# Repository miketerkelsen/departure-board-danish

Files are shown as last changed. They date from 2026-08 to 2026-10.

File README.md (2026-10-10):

# departures-board 

This is an ESP32 based Departures Board for Danish public transport, using data from [Rejseplanen](https://www.rejseplanen.dk) (API 2.0), which covers almost all of Denmark's trains, S-tog, letbane/light rail and buses. It replicates the look of a real station departure board. This implementation uses a 3.12" OLED display panel with SSD1322 display controller onboard, plus an optional TTP223 touch sensor. STL files are also provided for 3D printing the custom desktop case.

## Features
* All processing is done onboard by the ESP32 processor, no middleware servers
* Support for a touch sensor to switch modes / stations / wake from screensaver
* Smooth animation matching real station departure boards
* Four board modes, all powered by Rejseplanen:
  * **Tog** - intercity/regional trains (IC, Lyntog, Regionaltog, Togbus, S-tog), filterable by train type
  * **S-tog** - a dedicated S-tog board with line-letter badges (e.g. A, C, Bx) and minute countdowns, so you can run it alongside Tog for the same or a different station
  * **Letbane** - light rail, with the current location of the next service optionally shown
  * **Bus** - bus stop departures
* Plus a Swedish mode, powered by [Trafiklab](https://www.trafiklab.se) (a separate, free API key):
  * **Tunnelbana** - Stockholm's metro, with round line badges (10, 11, 13, 14, 17, 18, 19), half-minute countdowns and the stops each train calls at. All on-screen text is Swedish. Tick Denmark and/or Sweden in the web configuration to choose which countries' modes are offered, and switch the board between them.
* Displays up to the next 9 departures with scheduled time, platform/track, destination, calling stations and expected/delayed departure time
* Optionally only show services heading towards a particular calling-at station (Tog mode)
* Scheduler and Carousel modes to automatically switch between any combination of configured stations/stops
* Fully-featured browser based configuration screens with live station search for all four modes
* Automatic firmware updates (optional), including daily update checks
* Displays the weather at the selected location (optional)
* Optionally display RSS headline feeds, with a built-in editor to add custom feeds
* Full-screen station clock (optional), including as a screensaver
* All on-screen text (including setup/error screens) is in Danish, with Danish and Swedish accented characters (æ ø å ä ö) supported
* STL files provided for a custom 3D printed case

## Quick Start

### What you'll need

1. An ESP32 D1 Mini board (or clone) - either USB-C or Micro-USB version with CH9102 recommended. For example, from [AliExpress](https://www.aliexpress.com/item/1005005972627549.html).
2. A 3.12" 256x64 OLED Display Panel with SSD1322 display controller onboard. For example, from [AliExpress](https://www.aliexpress.com/item/1005008558326731.html).
3. A 3D printed case using the STL files provided (see Credits below for where the original case design comes from). If you don't have a 3D printer, you can use a 3D print service, local library or group.
4. Optionally, a TTP223 touch sensor (for easily switching modes / stations). For example, from [AliExpress](https://www.aliexpress.com/item/1005007850732859.html). If fitted, the touch sensor should be glued to the inside of one of the walls of the top part of the case with the *sensor* side against the case.
5. A free Rejseplanen `accessId` from [Rejseplanen Labs](https://labs.rejseplanen.dk) - this is the only API key required, and covers all four board modes.
6. By default, weather data is sourced from Open-Meteo (no key needed). If you prefer to use OpenWeather (which usually provides slightly more localised weather conditions) you will need an OpenWeather Map API token (also free, sign up for a free developer account [here](https://home.openweathermap.org/users/sign_up)).
7. Some intermediate soldering skills.



### Preparing the OLED display for 4-Wire SPI Mode


As supplied, the display is usually shipped with 8-bit 80XX mode enabled. This needs to be changed to 4-Wire SPI mode by removing one link and adding another (the image shows where to make these changes on the rear of the circuit board).

### Wiring Guide

Solder the 4 SPI connections, plus power and ground. The wires **MUST** be soldered to the **BACK** of the ESP32 Mini board (the side without the components) to enable it to sit in place in the case. You can solder directly to the pins on the OLED screen or for the best fit (if you are a more experienced solderer) de-solder and remove the header pins and solder directly to the board. You cannot use Dupont connectors, they will not fit the custom case design.

| OLED Pin | ESP32 Mini Pin |
|:---|:---:|
| 1 VSS | GND |
| 2 VCC_IN | 3.3v |
| 4 D0/CLK | IO18 |
| 5 D1/DIN | IO23 |
| 14 D/C# | IO5 |
| 16 CS# | IO26 |

| TTP223 Pin | ESP32 Mini Pin |
|:---|:---:|
| 1 GND | GND |
| 2 I/O | IO34 |
| 3 VCC | 3.3v |



### Installing the firmware

The project uses the Arduino framework and the ESP32 v3.3.9 core. If you want to build from source, you'll need [PlatformIO](https://platformio.org). The software is designed for, and makes use of, a dual-core ESP32 processor. If you attempt to target and compile for a single core ESP32 variant the experience will be suboptimal at best.

You can download pre-compiled firmware images from the [releases](https://github.com/miketerkelsen/departure-board-danish/releases). These can be installed over the USB serial connection using [esptool](https://github.com/espressif/esptool). If you have python installed, install with *pip install esptool*. For convenience, a pre-compiled executable version for Windows is included [here](https://github.com/miketerkelsen/departure-board-danish/tree/main/esptool).

If the board is not recognised you are probably using a version with the CP2104 USB-to-Serial chip. Drivers for the CP2104 are [here](https://www.silabs.com/developer-tools/usb-to-uart-bridge-vcp-drivers?tab=downloads)

Attach the ESP32 Mini board via it's USB port and use the following command to flash the firmware:

```
esptool.py --chip esp32 --baud 460800 write_flash -z \
  0x1000 bootloader.bin \
  0xe000 boot_app0.bin \
  0x8000 partitions.bin \
  0x10000 firmware.bin
```

The tool should automatically find the correct serial port. If it fails to, you can manually specify the correct port by adding *--port COMx* (replace *COMx* with your actual port, e.g. COM3, /dev/ttyUSB0, etc.).

If using the pre-compiled esptool.exe version on Windows, save the esptool.exe and the four firmware (.bin) files to the same directory. Open a command prompt (Windows Key + R, type cmd and press enter) and change to the directory you saved the files into. Now type the following command on one line and press enter:
```
.\esptool --chip esp32 --baud 460800 write_flash -z 0x1000 bootloader.bin 0xe000 boot_app0.bin 0x8000 partitions.bin 0x10000 firmware.bin
```

Subsequent updates can be carried out automatically over-the-air or you can manually update from the Web GUI.

### First time configuration

WiFiManager is used to setup the initial WiFi connection on first boot. The ESP32 will broadcast a temporary WiFi network named "Departures Board" - connect to it and follow the on-screen instructions to join it to your own WiFi network.

Once the ESP32 has established an Internet connection, the next step is to enter your Rejseplanen API key (and, optionally, an OpenWeather Map key). Finally, select a station location for one of the four board modes - start typing the station name and valid choices will be shown as you type.

### Web GUI

At start-up, the ESP32's IP address is displayed. To change the station or to configure other miscellaneous settings, open the web page at that address.

- **Board Mode** - switch between Tog, S-tog, Letbane and Bus.
- **Station / S-tog Station / Letbane Stop / Bus Stop** - start typing a few characters of the name and select from the drop-down picker displayed. The field shown depends on the selected board mode.
- **Only show these train types** (Tog mode) - filter by category: IC, Lyntog (ICL), Regionaltog (Re), Togbus (rail-replacement bus) and S-tog.
- **Only show trains heading towards** (Tog mode) - optionally only show services heading towards a particular calling-at station.
- **Add to Scheduler** - adds the currently configured location to the scheduler (see Schedule tab) to switch based on time of day.
- **Add to Carousel** - adds the currently configured location to the carousel (see Schedule tab) to switch views after a period of time.

#### Options tab ####
- **Brightness** - adjusts the brightness of the OLED screen. Lowering it helps prevent burn-in.
- **Show the date on screen** - displays the date in the upper-right corner (useful if you're also using this as a desk clock).
- **Show current weather at station/bus stop** - optionally display weather conditions at the selected location.
- **Show station messages** (Tog/S-tog) - displays station and service status messages.
- **Show platform numbers if available** (Tog/S-tog) - deselecting this hides platform/track numbers.
- **Show service ordinal numbers** (Tog/S-tog) - displays "2nd", "3rd", "4th" etc. next to the service times.
- **Show service current location** (Letbane) - displays the origin of the primary service.
- **Wait for Calling at list to complete** (Tog/S-tog) - waits for the calling-at list to finish scrolling before changing the primary service.
- **Wait for Messages or RSS to complete** - waits for the current service message or RSS headline to finish scrolling before changing the primary service.
- **Full screen clock if no train services** - displays the full screen station clock if there are no scheduled services at the selected station.
- **Automatic firmware updates at startup** - automatically checks for and installs the latest firmware from this repository's [releases](https://github.com/miketerkelsen/departure-board-danish/releases) when the system starts up.
- **Daily check for firmware updates** - when enabled, the system also checks for and installs any updates just after midnight if the board is powered on.
- **Overnight sleep mode (screensaver)** - if you're running the board 24/7, this helps prevent screen burn-in overnight, with configurable start/end hours.
- **Switch off display during sleep mode** - turns off the display completely during sleep mode, otherwise displays the date & time.
- **Full screen clock during sleep mode** - displays the full screen station clock during sleep mode instead.

#### Schedule tab ####
- **Enable scheduler** - automatically switches between locations based on the configured time of each entry in the scheduler list (up to 5 entries).
- **Enable carousel** - automatically switches between locations based on the configured view time of each entry in the carousel list (up to 5 entries).

#### Advanced Tab ####
- **Enable touch sensor** - a tap switches between configured board modes, or wakes the board from sleep. If the Scheduler or Carousel is active, a tap switches to the next location instead. Requires an installed TTP223 sensor.
- **Wake from sleep by touch for** - if the board is in screensaver mode, a tap wakes it and it stays awake for the selected number of minutes (the timer resets on each tap).
- **Long press displays full screen clock** - a long tap switches to the full screen clock; a short tap reverts to normal operation.
- **Flip the display 180°** - rotates the display (the case design provides two different viewing angles depending on orientation).
- **Set custom hostname for board** - change the hostname from the default "DeparturesBoard", useful if you're running multiple boards.
- **Set custom (non-Danish) time zone** - only affects the clock display (see [below](#custom-time-zones) for details).
- **Suppress calling at / info messages** - turns off all horizontally scrolling text and RSS feeds (much lower functionality but less distracting).
- **Increase API refresh rate** - reduces the interval between data refreshes from every 90 seconds to every 45 seconds. Applies to all four modes; doubles Rejseplanen API usage, so worth leaving off if you're mindful of your API quota.
- **Show activity indicator during updates** - displays an icon while the board is communicating with Rejseplanen/weather/RSS.
- **Display RSS news headlines feed from** - shows the top headlines from the selected feed after other service messages. Use the RSS Feeds Editor to add your own feeds.
- **Prioritise RSS headlines feed** - displays headlines before other service messages.
- **Offset departures by** (Tog/S-tog) - displays future (or past) services offset by the selected time; does not affect the clock display.

A drop-down menu (top-right) adds the following options:
- **Check for Updates** - manually checks for and optionally installs any updates to the firmware. Also displays the release notes of the latest firmware.
- **Edit API Keys** - view/edit your Rejseplanen and OpenWeather Map API keys.
- **Edit RSS Feeds** - loads the RSS Feeds Editor where you can add/edit/delete custom headline feeds.
- **Clear WiFi Settings** - deletes the stored WiFi credentials and restarts in WiFiManager mode (useful to change WiFi network).
- **Restart System** - restarts the ESP32.

#### Other Web GUI Endpoints

A few other urls have been implemented, primarily for debugging/developer use:
- **/factoryreset** - deletes all configuration information, api keys and WiFi credentials. The entire setup process will need to be repeated.
- **/update** - for manual firmware updates. Download the latest binary from the [releases](https://github.com/miketerkelsen/departure-board-danish/releases). Only the **firmware.bin** file should be uploaded via */update*. The other .bin files are not used for upgrades. This method is *not* recommended for normal use.
- **/info** - displays some basic information about the current running state.
- **/formatffs** - formats the filing system, erasing the configuration files (but not the WiFi credentials).
- **/dir** - displays a (basic) directory listing of the file system with the ability to view/delete files.
- **/upload** - upload a file to the file system.
- **/control** - an endpoint for automation of sleep mode. Takes optional parameters *sleep* and *clock* - e.g. /control?sleep=1&clock=0 will force sleep mode and turn off the display completely. /control?sleep=0 will revert to normal operation. Always returns current state as json.

### Danish Rejseplanen Stop IDs
All four board modes use [Rejseplanen](https://www.rejseplanen.dk) (API 2.0). You'll need a free `accessId` from [Rejseplanen Labs](https://labs.rejseplanen.dk) - enter it as the "Rejseplanen API Key" on the API Keys screen. The web GUI's station search boxes handle finding stop IDs for you, but if you need to look one up manually: search for it on [rejseplanen.dk](https://www.rejseplanen.dk) and look at the departure board URL, or use a stop lookup tool such as [rejseplanen-cli](https://github.com/ndrdlc/rejseplanen-cli). Some stops (particularly letbane/light rail stops) have two IDs - one per direction of travel - but either one shows the full combined board with both directions, so it doesn't matter which you use. For example, Odense St. is `8600512` and Bolbro (Odense Letbane) is `8608704` or `8608754` - either works identically for Bolbro.

Danish æ/ø/å and Swedish ä/ö characters are supported directly on-screen (Swedish letters cover the occasional Swedish train passing through Denmark).

### Custom Time Zones
To set a custom time zone for the departure board clock, you will need to enter the POSIX time zone string for your location. Some examples are `CST6CDT,M3.2.0/2,M11.1.0/2` for Canada (Central Time), `AEST-10AEDT,M10.1.0,M4.1.0/3` for Australia (Eastern Time) and `CET-1CEST,M3.5.0,M10.5.0/3` for Denmark (Central European Time, the default). The easiest way to find the correct syntax is to ask your favourite AI chat engine *"What is the POSIX time zone string for ..."*. Note that changing the time zone only affects the clock (and date) display - service times are always shown in Danish local time, exactly as Rejseplanen returns them, regardless of the board's own clock time zone.

### Credits
This project is a Danish-focused fork of the original [Departures Board](https://github.com/gadec-uk/departures-board) by Gadec Software, including the OLED case design. This fork replaces the original UK Rail/Tube/Bus modes with Danish Rejseplanen-based modes (Tog, S-tog, Letbane, Bus) and translates the on-screen display to Danish.

### Licence
This work is licensed under **Creative Commons Attribution-NonCommercial-ShareAlike 4.0**. To view a copy of this licence, visit [https://creativecommons.org/licenses/by-nc-sa/4.0/](https://creativecommons.org/licenses/by-nc-sa/4.0/). Note: the terms of the licence prohibit commericial use of this work, this includes *any* reselling of the work in kit or assembled form for commercial gain.

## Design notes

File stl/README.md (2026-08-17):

# Departures Board Custom Case

This updated version of the custom case for the Departures Board is now compatible with both Micro-USB and USB-C versions of the processor board. The ESP32 D1 Mini processor is held securely in place by both halves of the case. The OLED screen should be a snug tight fit.  Optionally you may wish to fix the screen firmly in place with a few dabs from a hot glue gun (after fully testing!).

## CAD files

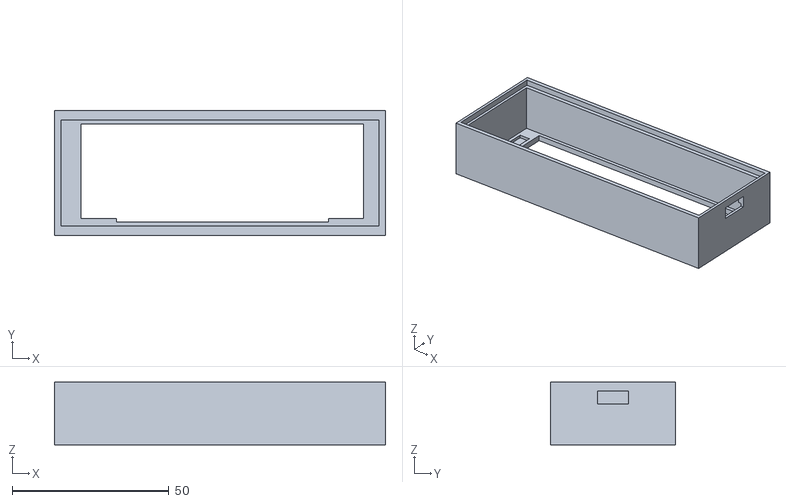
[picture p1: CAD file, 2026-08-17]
stl/Departures Board OLED Case Top v1.2.stl
105.5 x 39.7 x 20.0

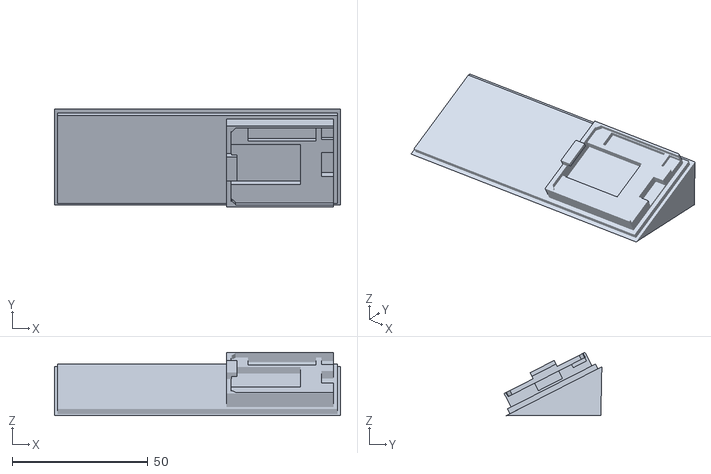
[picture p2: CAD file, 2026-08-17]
stl/Departures Board OLED Case Bottom v1.2.stl
105.5 x 36.1 x 23.4

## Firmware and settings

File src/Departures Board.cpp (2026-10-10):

/*
 * Departures Board (c) 2025-2026 Gadec Software
 *
 * https://github.com/gadec-uk/departures-board
 *
 * This work is licensed under Creative Commons Attribution-NonCommercial-ShareAlike 4.0 International.
 * To view a copy of this license, visit https://creativecommons.org/licenses/by-nc-sa/4.0/
 *
 * ESP32 "Mini" Board with 3.12" 256x64 OLED Display Panel with SSD1322 controller on-board.
 *
 * OLED PANEL     ESP32 MINI
 * 1 VSS          GND
 * 2 VCC_IN       3.3V
 * 4 D0/CLK       IO18
 * 5 D1/DIN       IO23
 * 14 D/C#        IO5
 * 16 CS#         IO26
 *
 * Optional TTP223 touch sensor connection:
 *
 * TTP223         ESP32 MINI
 * GND            GND
 * VCC            3.3V
 * I/O            IO34
 *
 */

#include <Arduino.h>
#include <WiFi.h>
#include <WiFiClientSecure.h>
#include <WiFiManager.h>
#include <AsyncTCP.h>
#include <ESPAsyncWebServer.h>
#include <StreamString.h>
#include <Ticker.h>
#include <HTTPClient.h>
#include <ESPmDNS.h>
#include <HTTPUpdateGitHub.h>
#include <FS.h>
#include <LittleFS.h>
#include <ArduinoJson.h>
#include <weatherClient.h>
#include <sharedDataStructs.h>
#include <responseCodes.h>
#include <boardText.h>
#include <rejseplanenClient.h>
#include <trafiklabClient.h>
#include <new>
#include <githubClient.h>
#include <rssClient.h>
#include <touchSensor.h>
#include <webgui/webgraphics.h>
#include <webgui/index.h>
#include <webgui/keys.h>
#include <webgui/editrss.h>
#include <webgui/rss.h>
#include <time.h>

#include <SPI.h>
#include <U8g2lib.h>

#define msDay 86400000 // 86400000 milliseconds in a day
#define msHour 3600000 // 3600000 milliseconds in an hour
#define msMin 60000 // 60000 milliseconds in a second

static AsyncWebServer server(80); // Hosting the Web GUI

// Shorthand for response formats
static const char contentTypeJson[] = "application/json";
static const char contentTypeText[] = "text/plain";
static const char contentTypeHtml[] = "text/html";

// Using NTP to set and maintain the clock
static struct tm timeinfo;
static const char defaultTimezone[] = "CET-1CEST,M3.5.0,M10.5.0/3"; // Denmark (CET/CEST)

// Default hostname
static const char defaultHostname[] = "DeparturesBoard";

// Local firmware updates via /update Web GUI
static const char updatePage[] =
"<script src='https://ajax.googleapis.com/ajax/libs/jquery/3.2.1/jquery.min.js'></script>"
"<html><body style=\"font-family:Helvetica,Arial,sans-serif\"><h2>Departures Board Manual Update</h2><p>Upload a <b>firmware.bin</b> file.</p>"
"<form method='POST' action='#' enctype='multipart/form-data' id='upload_form'>"
   "<input type='file' name='update'>"
        "<input type='submit' value='Update'>"
    "</form>"
 "<div id='prg'>progress: 0%</div>"
 "<script>"
  "$('form').submit(function(e){"
  "e.preventDefault();"
  "var form = $('#upload_form')[0];"
  "var data = new FormData(form);"
  " $.ajax({"
  "url: '/update',"
  "type: 'POST',"
  "data: data,"
  "contentType: false,"
  "processData:false,"
  "xhr: function() {"
  "var xhr = new window.XMLHttpRequest();"
  "xhr.upload.addEventListener('progress', function(evt) {"
  "if (evt.lengthComputable) {"
  "var per = evt.loaded / evt.total;"
  "$('#prg').html('Progress: ' + Math.round(per*100) + '%');"
  "}"
  "}, false);"
  "return xhr;"
  "},"
  "success:function(d, s) {"
  "console.log('success!')"
 "},"
 "error: function (a, b, c) {"
 "}"
 "});"
 "});"
 "</script></body></html>";

// /upload page
static const char uploadPage[] =
"<html><body style=\"font-family:Helvetica,Arial,sans-serif\">"
"<h2>Upload a file to the file system</h2><form method='post' enctype='multipart/form-data'><input type='file' name='name'>"
"<input class='button' type='submit' value='Upload'></form></body></html>";

// /success page
static const char successPage[] =
"<html><body style=\"font-family:Helvetica,Arial,sans-serif\"><h3>Upload completed successfully.</h3>\n"
"<p><a href=\"/dir\">List file system directory</a></p>\n"
"<h2>Upload another file</h2><form method=\"post\" action=\"/upload\" enctype=\"multipart/form-data\"><input type=\"file\" name=\"name\"><input class=\"button\" type=\"submit\" value=\"Upload\"></form>\n"
"</body></html>";

#define SCREEN_WIDTH 256 // OLED display width, in pixels
#define SCREEN_HEIGHT 64 // OLED display height, in pixels
#define DIMMED_BRIGHTNESS 1 // OLED display brightness level when in sleep/screensaver mode

U8G2_SSD1322_NHD_256X64_F_4W_HW_SPI u8g2(U8G2_R0, /* cs=*/ GPIO_NUM_26, /* dc=*/ GPIO_NUM_5, /* reset=*/ U8X8_PIN_NONE);

// Vertical line positions on the OLED display (National Rail)
#define LINE0 0
#define LINE1 13
#define LINE2 28
#define LINE3 41
#define LINE4 55

// Vertical line positions on the OLED display (Underground)
#define ULINE0 0
#define ULINE1 15
#define ULINE2 28
#define ULINE3 41
#define ULINE4 56

static Ticker restartTimer; // used to schedule reboots

//
// Custom fonts - replicas of those used on the real display boards
//
static const uint8_t NatRailSmall9[1329] U8G2_FONT_SECTION("NatRailSmall9") =
  "\221\0\3\2\4\4\4\5\5\11\11\0\0\11\0\11\2\1E\2\214\5\30 \5\0\230)!\7q("
  "%\6%\42\10\63h)\22K\0#\17u(mJI\62(\225A)%\11\0$\14u(\255\262"
  "\245\266%\311\26\1%\14t(+\42E\212\244H\221\2&\16u(m\244\222\224$R\22EJ\0"
  "'\6\61h%\6(\11s(\251\222R\255\0)\11s()\262R\245\4*\12U\70-\222\312b"
  "Y\32+\12U\70\255\302h\220\302\10,\7\62\10g\22\5-\6\23X)\6.\6\21(%\2/"
  "\13t(\353\42)\222\42)\3\60\12u(m\226\314[\262\0\61\11s)m\22\251\313\0\62\13u"
  "(m\226,\314\332\6\1\63\14u(m\226,\214T-Y\0\64\15u(\355\62))%\203\26&"
  "\0\65\13u(-\216C\32j\311\2\66\15u(m\226L\34\222LK\26\0\67\12u(-\6\61"
  "+\66\1\70\15u(m\226LK\226LK\26\0\71\15u(m\226LK\206PK\26\0:\7A"
  "\70%\242\0;\7R(gR\5<\10t(\353\242\306\6=\10\64H+\206p\10>\11t(+"
  "\302\246\66\0?\14u(m\226,\214\264\34\212\0@\14u(m\226\314\222(C\272\0A\13u("
  "m\226L\33\206\314\26B\15u(-\206$\323\6%\323\6\5C\13u(m\226LlK\26\0D"
  "\13u(-\206$\363\66(\0E\13u(-\216\341\220\204\341 F\13u(-\216\341\220\204E\0"
  "G\15u(m\226LL\206LK\26\0H\13u(-\62\333\60d\266\0I\7q(%\16\1J"
  "\11u(-;j\311\2K\15u(-\62))iIT\311\2L\11u(-\302\36\7\1M\13"
  "u(-\262eI\64\267\0N\13u(-\262II\244\315\26O\12u(m\226\314[\262\0P\14"
  "u(-\206$\323\6%,\2Q\13\225\10m\226\314[\62\246\1R\15u(-\206$\323\6\245T"
  "\311\2S\13u(m\226L]\265d\1T\11u(-\6)\354\11U\11u(-\62\337\222\5V"
  "\12u(-\62oI-\2W\13u(-\62\227DIn\1X\14u(-\62-\251UjZ\0"
  "Y\13u(-\62-\251\205M\0Z\12u(-\6\61\353\70\10[\10r('\226.\2\134\12t"
  "(+\62-\323\62-]\10r(\63\224.\3^\6#xi\32_\7\24\30+\206\0`\7\42x"
  "'\242\0a\12U(m\326d\320\222!b\13u(-\302\212I\323\6\5c\11U(m\6\261:"
  "\4d\13u(-+\246MK\206\0e\12U(m\226l\30\322!f\12t(\253*\245)+\1"
  "g\14u\10m\6\315\226\14\341\240\0h\12u(-\302\212I\263\5i\7q(%\222Aj\13\224"
  "\10\353r k\223\22\5k\13t(+\262\222\222HI)l\7q(%\16\1m\12U(m\272"
  "(\211\246\5n\11U(-\22\223f\13o\12U(m\226\314\226,\0p\14u\10-\206$\263\15"
  "J\30\2q\13u\10m\6\315\226\14a\1r\11U(-\22\223X\4s\11U(m\6\365\240\0"
  "t\13t(k\262hH\262\242\0u\11U(-\62'E\11v\12U(-\62[R\213\0w\14"
  "U(-\62%Q\22\245\13\0x\12U(-\262\244V\251\5y\13u\10-\62\267d\10\7\5z"
  "\11U(-\6\255m\20{\12s(\251\222(\311\242,|\7q(%\16\1}\13s()\262("
  "K\242$\2~\10%XmL\11\0\15u(-\222\254R\214\222(Q\12\200\5\0\10!\201\14"
  "e)\361\222A\213\262A\311\0\202\10B\10g*\12\0\203\5\0\10!\204\11D\10kzQ\22\0"
  "\205\7\25(-\222\2\206\15v(o\206$\64\16\17I\224\0\207\16w(\261\266\244)\262\250I\226"
  "M\0\210\21\210\30\63\323!\213\222d\213\262\245\224\15i\10\211\5\0\10!\212\5\0\10!\213\5\0"
  "\10!\214\5\0\10!\215\15u(/NK\242)C\62\14\2\216\16u(/\16\221\62(\203\42\15"
  "C\0\217\14w(\61\336\246\310\242n\303\1\220\6\63N?\36\221\7\62h'\222(\222\7\62hg"
  "\22\5\223\10\64h+\222\246$\224\10\64hkZ\224\4\225\6\63H)\36\226\7\25X-\6\1\227"
  "\5\0\10!\230\5\0\10!\231\5\0\10!\232\5\0\10!\233\5\0\10!\234\5\0\10!\235\5\0"
  "\10!\236\5\0\10!\237\5\0\10!\240\5\0\10!\241\5\0\10!\242\5\0\10!\243\14u(\255"
  "\244J\66Da\66\10\244\5\0\10!\245\5\0\10!\246\5\0\10!\247\5\0\10!\250\5\0\10!"
  "\251\5\0\10!\252\5\0\10!\253\5\0\10!\254\5\0\10!\255\5\0\10!\256\5\0\10!\257\5"
  "\0\10!\260\12DXk\224HJ\24\0\0\0\0";

static uint8_t NatRailTall12[1102] U8G2_FONT_SECTION("NatRailTall12") =
  "c\0\3\2\4\4\2\5\5\11\14\0\375\11\375\11\0\1Q\2\235\4\65 \5\0f\12!\7\221B"
  "\211C\22\42\7#^\212D\11#\21\225B\233R\222\14J)\211\222dPJI\2$\17\225B\253"
  "l)%\331\226DI\262E\0%\12\225B\313i\312:\35\1&\20\225B\33\251\22%Q$%\211"
  "\224D\221\22'\6!^\11\1(\11\223B\252\244\324\255\0)\11\223B\212\254\324\245\4*\14uF"
  "\253Je\261,M\21\0+\12UJ\253\60\32\244\60\2,\7\62\272\231D\1-\6\23R\212\1."
  "\6!B\11\1/\11\225B\313\266\216E\0\60\12\225B\233%\363[\262\0\61\11\223C\233D\352\313"
  "\0\62\13\225B\233%\13k\35\7\1\63\15\225B\233%\13Kj\250%\13\0\64\16\225B\273LJ"
  "JI\224\14ZX\1\65\15\225B\213c\70\244a\250%\13\0\66\15\225B\233%\23\303!\311l\311"
  "\2\67\15\225B\213A\254\205Y\230\205\31\0\70\15\225B\233%\263%KfK\26\0\71\15\225B\233"
  "%\263%C\30j\311\2:\6QJ\11E;\10b\306\231Z\242\0<\10t\306\272\250\261\1=\10"
  "\64\316\212!\34\2>\10t\306\212\260\251\15?\14\225B\233%\13k\305\34\212\0@\16\225B\233%"
  "\263$J\242\14a\272\0A\13\225B\233%\263\15C\346\26B\15\225B\213!\311l\203\222\331\6\5"
  "C\13\225B\233%\23{K\26\0D\13\225B\213!\311\374\66(\0E\13\225B\213cqH\302\342"
  " F\13\225B\213cqH\302F\0G\14\225B\233%\23K\233-Y\0H\13\225B\213\314m\30"
  "\62\267\0I\6\221B\211\7J\11\225B\313>j\311\2K\16\225B\213\60\223\222\222\246%Q%\13"
  "L\11\225B\213\260\37\7\1M\14\225B\213lY\22%\321\274\5N\15\225B\213l\232\224DI\244"
  "\233\26O\12\225B\233%\363[\262\0P\14\225B\213!\311l\203\22\66\2Q\13\265:\233%\363["
  "\62\246\1R\16\225B\213!\311l\203R\252dZ\0S\14\225B\233%S\325\242\226,\0T\11\225"
  "B\213A\12\373\11U\11\225B\213\314\337\222\5V\12\225B\213\314oI-\2W\13\225B\213\314\227"
  "DIn\1X\16\225B\213LKJIV\211\222\232\26Y\14\225B\213LKJI\26v\2Z\13"
  "\225B\213A\254u\14\7\1[\10\222\302\211\245/\2\134\11\225B\213\260\332\261\0]\10\222\302\11\245"
  "/\3^\6#^\232\6_\6\25>\213A`\6\42\336\211(a\13eB\233\65\31\64-\31\2b"
  "\14\225B\213\260\305\244i\223\242\0c\11eB\233Al\35\2d\13\225B\313\26\323fR\224\0e"
  "\14eB\233%\33\206\60K\26\0f\13\224\302*%\213\206$\353\4g\15\225\66\33\323fR\224P"
  "K\26\0h\12\225B\213\260\305\244\271\5i\7\201B\211d\30j\13\264\266\272\34\310z\223\22\5k"
  "\15\225B\213\260))iIT\311\2l\6\221B\211\7m\15eB\13\245EI\224DI\224\2n"
  "\11eB\213\304\244\271\5o\12eB\233%sK\26\0p\15\225\66\213\304\244i\223\242\204E\0q"
  "\13\225\66\33\323fR\224\260\1r\11eB\213\304$\66\2s\12eB\233%]\265d\1t\12\204"
  "\302\232,\32\222\254Qu\11eB\213\314\223\242\4v\14eB\213LKJI\26F\0w\16eB"
  "\213$Q\22%Q\22\245\13\0x\13eB\213,\251\205YR\13y\14\225\66\213\314\223\242\204Z\262"
  "\0z\12eB\213A\314\332\6\1{\21\227B\234,\321\226\245\247\310\242&Y\222,\1|\6\221B"
  "\213\7}\17\266\66\273\70\31\306:\26\206\303\22g\0~\21\226\302\233!\31\206P\34\36\24e\30\222"
  "(\1\16\226\302\213$\314\224(\315\222,\351?\200\24\231B\255AK\223L\222B)\224BMJ"
  "\322l\220\0\201\24\231>\255AK\223,\323\62-\323\26\35H\322l\220\0\202\22\231>\335t\320*"
  "\311\30\245Q\270\324\262AM\1\0\0\0";

static const uint8_t NatRailClockSmall7[137] U8G2_FONT_SECTION("NatRailClockSmall7") =
  "\12\0\3\3\3\3\3\1\5\7\7\0\0\7\0\7\0\0\0\0\0\0p\60\12?\343Td\274I*"
  "\0\61\10\274\343HF\272\20\62\13?\343TdRIE*=\63\14?\343TdR\331\230&\251\0"
  "\64\14?\343\315H\22%\311Q*\1\65\13?c\34\244f)MR\1\66\14?\343TdT\213\214"
  "&\251\0\67\11?c\134\205Z\325\0\70\15?\343Td\64IEF\223T\0\71\14?\343Td\64"
  "\211\225&\251\0\0\0\0";

static const uint8_t NatRailClockLarge9[177] U8G2_FONT_SECTION("NatRailClockLarge9") =
  "\13\0\4\3\4\4\3\2\5\11\11\0\0\11\0\11\0\0\0\0\0\0\230\60\13\231T\307\205\24\277\222"
  "\270\0\61\11\224W\207\304\210\276 \62\16\231T\307\205\224\234\212\13\71u\7\2\63\17\231T\307\205\224"
  "\234\232B\71*\211\13\0\64\23\231T\327\24\221\204\214\210\32\11!\211\3\61\71\11\0\65\20\231T\307"
  "\301\234\334A\240\34\25\225\304\5\0\66\20\231T\307\205\24\235\334A\204\24+\211\13\0\67\14\231T\303"
  "\201\234\252Ur\32\1\70\17\231T\307\205\24+\211\13)V\22\27\0\71\20\231T\307\205\24+\211\203"
  "\70\71*\211\13\0:\7r\235\2\31\1\0\0\0";

static const uint8_t Underground10[1335] U8G2_FONT_SECTION("Underground10") =
  "\221\0\3\2\3\4\4\5\5\11\12\0\377\11\377\11\0\1^\2\310\5\36 \5\0\314\25!\7I\204"
  "\22\207$\42\7\23\274\24\211\22#\21M\204\66\245$\31\224R\22%\311\240\224\222\4$\17M\204V"
  "\331RJ\262-\211\222d\213\0%\12M\204\226\323\224u:\2&\17F\204\67Z\324\246E\211\226D"
  "I\42\5'\10\42\254\23C\242\0(\10J\204\63J\237\2)\11J\204\23Q\322\213\2*\14=\214"
  "V\225\312AY\232\42\0+\12-\224Va\64Ha\4,\10\42|\23C\242\0-\7\15\244\26\203"
  "\0.\7\22\204\23C\0/\10?\214\327i\237\1\60\14N\204\67C\22\372\61\31\22\0\61\7J\205"
  "\67K?\62\14N\204\67C\22\246\305\216\303\0\63\16N\204\67C\22\246\245\71\25\223!\1\64\16N"
  "\204\227\241\226D\225,\31\306\264\2\65\16N\204\27\207\64\35\344\64\25\223!\1\66\17N\204\67C\22"
  "\252\351\240\204\306dH\0\67\12N\204\27\327b\257)\0\70\17N\204\67C\22\32\223!\11\215\311\220"
  "\0\71\17N\204\67C\22\32\223AM\305dH\0:\10\62\214\23C\70\4;\11:\204\23C\250("
  "\0<\10<\214uQc\3=\10\34\234\25C\70\4>\11<\214\25aS\33\0?\15M\204\66K"
  "\246\205Y\61\207\42\0@\16M\204\66KfI\224D\31\302t\1A\14N\204\67C\22\32\207At"
  "\14B\16N\204\27\203\22\32\207%\64\16\13\0C\14N\204\67C\22\252=&C\2D\13N\204\27"
  "\203\22\372qX\0E\14N\204\27\207\264:\14iu\30F\14N\204\27\207\264:\14i+\0G\16"
  "N\204\67C\22\252\225A\64&C\2H\13N\204\27\241\343\60\210\216\1I\11K\204\24K\324\227\1"
  "J\12M\204\226=jZ\262\0K\20N\204\27\241\226D\225LL\262\250\226\204\1L\11N\204\27i"
  "\277\16\3M\16O\204\30\351\266T\244H\212T\327\0N\15N\204\27\241\270)\221\224h\243\61O\14"
  "N\204\67C\22\372\61\31\22\0P\14N\204\27\203\22\32\207%m\5Q\14V|\67C\22\372)I"
  "\206\70R\16N\204\27\203\22\32\207\245\26\325\222\60S\17N\204\67C\22\252\361\20\247b\62$\0T"
  "\12O\204\30\207,\356\67\0U\12N\204\27\241?&C\2V\14O\204\30\251\257IVI\63\0W"
  "\16O\204\30\251\247H\212\244H\351\226\0X\16O\204\30\251\232d\225\264\222UR\65Y\14O\204\30"
  "i\222U\322\270\67\0Z\13O\204\30\207\70\355\363\60\4[\10J\204\23K_\4\134\11M\204\26a"
  "\265c\1]\10J\204\23J_\6^\6\23\274\64\15_\7\15|\26\203\0`\7\42\254\23\203\24a"
  "\13\65\214\66k\62hZ\62\4b\14E\214\26a\70$\231\333\240\0c\12\65\214\66K&\326\222\5"
  "d\13E\214\226\225AsK\206\0e\14\65\214\66K\66\14a\226,\0f\13L\204UJ\26MY"
  "'\0g\14E|\66K\346\226\14a\262\0h\13M\204\26a\70$\231o\1i\7A\214\22\311\60"
  "j\11S|Ti\324\323\2k\15E\214\26a))iIT\311\2l\10C\214\24Q\337\4m\16"
  "\67\214\30\213\22ER$ER$\25n\11\65\214\26C\222y\13o\12\65\214\66K\346\226,\0p"
  "\14E|\26C\222\271\15J\30\2q\13E|\66K\346\226\14a\1r\12\64\214\25\311\20em\0"
  "s\12\65\214\66K\272j\311\2t\13D\214\65Y\64$Y\243\0u\11\65\214\26\231\267d\10v\12"
  "\65\214\26\231[R\213\0w\13\67\214\30\251S\244tK\0x\13\65\214\26YR\13\263\244\26y\13"
  "E|\26\231\267d\10\7\5z\12\65\214\26\203V\314\262A{\13K\204TIT\311\242Z\0|\6"
  "I\204\26\17}\13K\204\24YTK\242J\4~\21N\204\67C\62\14\241\70<(\312\60$Q\2"
  "\16N\204\27I\230)Q\232%Y\322\200\5\0\204\20\201\10\25\204\26I\242\24\202\5\0\204\20"
  "\203\5\0\204\20\204\5\0\204\20\205\5\0\204\20\206\5\0\204\20\207\5\0\204\20\210\5\0\204\20\211\5"
  "\0\204\20\212\5\0\204\20\213\5\0\204\20\214\5\0\204\20\215\5\0\204\20\216\5\0\204\20\217\5\0\204"
  "\20\220\6\33\237\37\17\221\5\0\204\20\222\5\0\204\20\223\5\0\204\20\224\5\0\204\20\225\5\0\204\20"
  "\226\5\0\204\20\227\5\0\204\20\230\5\0\204\20\231\5\0\204\20\232\5\0\204\20\233\5\0\204\20\234\5"
  "\0\204\20\235\5\0\204\20\236\5\0\204\20\237\5\0\204\20\240\5\0\204\20\241\5\0\204\20\242\5\0\204"
  "\20\243\14=\214VR%\33\242\60\33\4\244\5\0\204\20\245\5\0\204\20\246\5\0\204\20\247\5\0\204"
  "\20\250\5\0\204\20\251\5\0\204\20\252\5\0\204\20\253\5\0\204\20\254\5\0\204\20\255\5\0\204\20\256"
  "\5\0\204\20\257\5\0\204\20\260\12-\244\66KfK\26\0\0\0\0";

static const uint8_t UndergroundClock8[150] U8G2_FONT_SECTION("UndergroundClock8") =
  "\13\0\3\3\3\4\2\2\5\7\10\0\0\10\0\10\0\0\0\0\0\0}\60\12G\305\251\310\370&\251"
  "\0\61\10\304\305\222\234\364\0\62\15G\305\251\310\244B\331L(;\10\63\15G\305\251\310\244\42\62\215"
  "&\251\0\64\15G\305\24\316H\22%\311Q*\1\65\14G\305\70\310\250f\32MR\1\66\14G\305"
  "\251\310\250\26\31\233\244\2\67\12G\305\70\310\204z\225\2\70\15G\305\251\310h\222\212\214MR\1\71"
  "\15G\305\251\310h\22+\215&\251\0:\6\262\257 \22\0\0\0";
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
void loop(void) {

  if (touchEnabled) button.updateTouchState();

  if (button.wasShortTapped()) {
    if (isSleeping) {
      if (NSEclockIsActive) NSEclockIsActive = false;
      else forcedAwake = true;
    } else {
      switchToNextMode();
    }
  } else if (button.wasLongTapped() && longPressClock) {
    NSEclockIsActive = !NSEclockIsActive;
  }

  // Heap fragmentation self-heal. The secure fetch needs one ~20KB contiguous block (see
  // MIN_SAFE_HEAP_FOR_FETCH); after hours of TLS handshakes the free memory can still total 45KB+ yet be
  // in pieces too small for that, at which point every fetch is skipped and the board runs on stale data
  // forever (seen: largest block 2.6KB, nothing fetched for 13 minutes, until someone power-cycled it).
  // Fragmentation never clears by itself, so if it has blocked fetching for ten solid minutes, restart.
  // Checked only every 10s; the restart happens between fetches so it can't interrupt one mid-flight.
  static unsigned long lowHeapSince = 0, nextHeapCheck = 0;
  if (millis() > nextHeapCheck) {
    nextHeapCheck = millis() + 10000UL;
    if (heap_caps_get_largest_free_block(MALLOC_CAP_8BIT) < MIN_SAFE_HEAP_FOR_FETCH) {
      if (!lowHeapSince) lowHeapSince = millis();
      else if (millis() - lowHeapSince > 600000UL && !fetchInProgress) ESP.restart();
    } else lowHeapSince = 0;
  }

  if (millis()-lastTimeUpdate >= 100) {
    // Update the current time
    int prevSecond = timeinfo.tm_sec;
    if (getLocalTime(&timeinfo)) {
      sprintf(currentTime,"%02d:%02d:%02d",timeinfo.tm_hour,timeinfo.tm_min,timeinfo.tm_sec);
      lastTimeUpdate = millis();
      if (millis()>3888000000 && timeinfo.tm_hour==3) ESP.restart(); // Reboot every 45 days at 3am
      if (isSleeping && (useNSEclockForSleep || NSEclockIsActive) && prevSecond != timeinfo.tm_sec) drawNSEclock();  // Update the large clock
    }
  }

  // Check for firmware updates daily if enabled
  if (dailyUpdateCheck && !fetchInProgress && millis()>fwUpdateCheckTimer) {
    fwUpdateCheckTimer = millis() + 3300000 + random(600000); // check again in 55 to 65 mins
    if (timeinfo.tm_mday != prevUpdateCheckDay) {
      if (ghUpdate.getLatestRelease()==UPD_SUCCESS) {
        checkForFirmwareUpdate();
      }
      prevUpdateCheckDay = timeinfo.tm_mday;
    }
  }

  bool wasSleeping = isSleeping;
  isSleeping = isSnoozing();

  if (isSleeping && !useNSEclockForSleep && !NSEclockIsActive && millis()>timer) {       // If the "screensaver" is active, change the screen every 8 seconds
    drawSleepingScreen();
    timer=millis() + SCREENSAVERINTERVAL;
  } else if (wasSleeping && !isSleeping) {
    // Exit sleep mode cleanly
    softResetBoard(MODE_LOADCONFIG);
  } else if (isSleeping && !wasSleeping && useNSEclockForSleep && !NSEclockIsActive) u8g2.setContrast(DIMMED_BRIGHTNESS);

  // WiFi Status icon
  if (WiFi.status() != WL_CONNECTED && wifiConnected) {
    wifiConnected=false;
    u8g2.setFont(NatRailSmall9);
    u8g2.drawStr(0,56,"\x7F");  // No Wifi Icon
    u8g2.updateDisplayArea(0,7,1,1);
  } else if (WiFi.status() == WL_CONNECTED && !wifiConnected) {
    wifiConnected=true;
    blankArea(0,57,5,7);
    u8g2.updateDisplayArea(0,7,1,1);
    updateMyUrl();  // in case our IP changed
  }

  // Force a manual reset if we've been disconnected for more than 10 secs
  if (WiFi.status() != WL_CONNECTED && millis() > lastWiFiReconnect+10000) {
    WiFi.disconnect();
    delay(100);
    WiFi.reconnect();
    lastWiFiReconnect=millis();
  }

  switch (boardMode) {
    case MODE_DKRAIL:
      departureBoardLoop();
      break;

    case MODE_LETBANE:
      undergroundArrivalsLoop();
      break;

    case MODE_DKBUS:
      if (strcmp(locationCode,ODENSE_ST_ID)==0) odenseBusLoop(); else busDeparturesLoop();
      break;

    case MODE_STOG:
      departureBoardLoop();
      break;

    case MODE_METRO:
      departureBoardLoop();
      break;

    case MODE_SE_METRO:
      departureBoardLoop();
      break;
  }

  if (manualUpdateCheck && !fetchInProgress) doManualOtaCheck();

  if (rssEnabled && boardMode != MODE_DKBUS && millis() > nextRssUpdate && !fetchInProgress && !isSleeping && wifiConnected) {
    // Start an RSS Update on Core 0
    fetchMode = FETCH_RSS;
    fetchInProgress = true;
    xTaskNotifyGive(fetchTaskHandle);
  }

  if (rssFetchComplete) {
    // Background fetch has completed
    rssFetchComplete = false;
    if (lastRssUpdateResult == UPD_SUCCESS) buildRssMessage();
  }

  if (weatherEnabled && millis()>nextWeatherUpdate && !fetchInProgress && locationLat && locationLon && !isSleeping && wifiConnected) {
    // Start a weather update on Core 0
    fetchMode = FETCH_WEATHER;
    fetchInProgress = true;
    xTaskNotifyGive(fetchTaskHandle);
  }

  if (weatherFetchComplete) {
    weatherFetchComplete = false;
    if (lastWeatherUpdateResult == UPD_SUCCESS) {
      strlcpy(weatherMsg,currentWeather.currentWeatherMessage,MAXWEATHERSIZE);
    } else {
      weatherMsg[0] = '\0';
    }
  }

  if (softResetNeeded && !fetchInProgress) {
    softResetNeeded=false;
    softResetBoard(MODE_LOADCONFIG);
  }

  if ((schedulerActive || (carouselActive && numCarouselSlots>1)) && !isSleeping && !fetchInProgress && millis() > nextSchedulerCheck) {
    int nowTime = getTimeInMinutes();
    if ((activeSlotEventTime < nextSlotEventTime && nowTime >= nextSlotEventTime) || (activeSlotEventTime > nextSlotEventTime && nowTime < activeSlotEventTime && nowTime >= nextSlotEventTime)) {
      if (carouselActive) currentCarouselSlot = (currentCarouselSlot + 1) % numCarouselSlots;
      softResetBoard(MODE_LOADCONFIG);
    }
    nextSchedulerCheck = millis() + 10000;  // ten seconds
  }

}

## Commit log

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2026-08-17 Add DK Bus mode for touch-cycling train/bus/tram at one station
    - New MODE_DKBUS (bitmask 32 = Bus, catCode 5), mirroring the UK bus
    board layout via rejseplanenClient, same pattern as DKRAIL/LETBANE
    - Wired through every mode switch site (loadSlot cycle + fields,
    softResetBoard, fetchDeparturesTask, drawStationHeader, updateBusDepartures,
    loop dispatch, /info, error screens, RSS exclusions)
    - Also fixed a gap from the original DKRAIL/LETBANE work: the boot-time
    init block in setup() never had DKRAIL/LETBANE cases either - added
    DKRAIL/LETBANE/DKBUS there too
    - Danish "Forventet"/"Aflyst"/"Rettidig" status text and "no scheduled
    services" message translated for DK Bus, matching D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
    [Departures Board.cpp]
2026-08-17 Fix DK Bus etd overflow and switch Letbane to computed minutes-remaining
    - drawBusService(): etdWidth was hardcoded to 47px, sized for the short
    English "Exp HH:MM" - the much longer Danish "Forventet HH:MM" ran
    past the right edge of the screen. Now measured dynamically for
    MODE_DKBUS via getStringWidth(), matching the pattern already used
    for the cancelled/on-time text branch.
    - drawUndergroundService(): Letbane now shows a computed "X min"/"Nu"
    countdown (derived from each service's time vs. the board's own
    clock) instead of a bare clock time, matching the tube board's style
    more closely per user preference - Rejseplanen doesn't provide a
    live countdown value directly, unl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
    [Departures Board.cpp]
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2026-08-17 Switch Danish accent glyphs to per-character mixing; remove Rejseplanen attribution
    - Replace the earlier whole-font-swap approach for aeoeaa/AEOEAA rendering with
    character-level mixing (drawMixedStr/getMixedStringWidth/centreMixedText/
    drawTruncatedMixedText): the original hand-built fonts (NatRailSmall9,
    NatRailTall12, Underground10) are kept as the base font everywhere, and only
    the six accented bytes borrow a matching-height stock U8g2 font
    (u8g2_font_5x8_tf / _6x12_tf / _6x10_tf) for that single glyph. Fixes the
    reported scrolling-text glitch, which was a font-height mismatch (10px stock
    font vs a hardcoded 9px blankArea clear) leaving ghost pixel rows.
    - Apply the mixed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
    [Departures Board.cpp]
2026-08-17 Fix screensaver date running off screen edge
    drawSleepingScreen() measured sysDate's width with whatever font happened to
    be active beforehand (line 912) and then with NatRailClockLarge9 - the big
    clock digit font, not the one sysDate is actually drawn with (line 915) -
    before finally switching to NatRailSmall9 to draw it. The mismeasured width
    fed into the random x-position calculation, so the string (most visibly
    Danish full month names like 'august'/'september') could run past the right
    edge of the screen. Now measures with NatRailSmall9 up front, matching the
    font used to draw it.
    [Departures Board.cpp]
2026-08-17 Skip the dead line-3 cycle slot left by removing DK Rail attribution
    departureBoardLoop()'s additional-service rotation assumed the mandatory
    attribution slot always existed beyond the departure list, so it kept
    cycling through a now-blank slot for DK Rail (which has no attribution and,
    when weather is off, no weather message either) before wrapping back to the
    2nd departure - showing as a black gap between the 9th and 2nd departures.
    Rollover now sizes to the number of extra slots that actually have content
    (weather if enabled, attribution only for non-DK-Rail modes), so DK Rail
    with no weather skips straight from the last departure back to the 2nd.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
    [Departures Board.cpp]
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2026-08-17 Fix getMixedStringWidth systematically under-measuring text width
    u8g2.getStrWidth() (called per-character in a loop) special-cases the LAST
    character of whatever string it's given: it measures that one character's
    tight glyph pixel width instead of its full advance width, to avoid counting
    trailing letter-spacing past the true end of a string. Looping getStrWidth()
    over one-character substrings (as getMixedStringWidth did) makes every single
    character get that tight treatment instead of just the true last one, so the
    returned total undercounts the width drawMixedStr() actually draws (which
    sums the full per-glyph advance width throughout, matching what a single
    whole-string drawStr() call w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
    [Departures Board.cpp]
2026-08-17 Fix remaining off-by-one in DK Rail line-3 rollover (still-blank slot)
    The extraSlots rollover from the previous fix counted the right number of
    "extra" content slots (weather/attribution) but compared with '>' instead of
    '>=' against numServices+extraSlots - the extra slots actually occupy indices
    numServices..numServices+extraSlots-1, so '>' let line3Service reach one
    index past the last real slot before wrapping, regardless of extraSlots.
    That's what still showed as a blank 3rd-row beat between the last departure
    and the 2nd on DK Rail even after the earlier fix. Using '>=' wraps exactly
    at the right point - straight from the last departure back to the 2nd when
    there's no weather message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
    [Departures Board.cpp]
2026-08-17 Fix Danish accent glyph size and vertical alignment
    Two related issues with the mixed-glyph rendering (drawMixedStr/
    getMixedStringWidth):
    1. Root cause of the vertical misalignment (only obviously visible on the
    primary departure line): the board runs in setFontPosTop()+
    setFontRefHeightAll() mode, and u8g2_SetFont() recalculates u8g2's
    internal vertical reference point (font_ref_ascent) from whichever font is
    currently active every time it's called. Swapping to the accent font
    mid-string and back was silently shifting each accented character up or
    down relative to its neighbours by however much the two fonts' computed
    reference ascents differ - e.g. NatRailTall12 vs t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
    [Departures Board.cpp]
2026-08-18 Fix Danish accent glyph size and vertical alignment
    reference ascents differ. drawMixedStr now reads u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
    [Departures Board.cpp]
2026-08-18 Fix per-glyph vertical offset causing specifically o/O to sit low
    Root cause finally identified precisely: u8g2 positions each glyph using
    TWO separate corrections layered on top of each other -
    1. A font-level "reference ascent" (font_ref_ascent), recalculated whenever
    setFont() runs - this is what the previous fix (baseAscent -
    accentFontAscent) already corrected for.
    2. A PER-GLYPH (height, y-offset) pair, individually encoded per character
    and applied via "target_y -= height+y_offset" inside
    u8g2_font_decode_glyph() - not accounted for at all until now.
    Decoded these per-glyph values directly (u8g2's public API only exposes a
    glyph's x-offset/advance-width, silently discardi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
    [Departures Board.cpp]
2026-08-18 Ping-pong scroll long destination names instead of truncating with "..."
    Applies to the rail board layout (shared by MODE_RAIL and MODE_DKRAIL): the
    primary departure, the static 2nd departure (noScrolling mode), and the
    rotating "other departures" slot. Each gets its own destScrollState so their
    animations track independently and don't clash with each other or with the
    existing scroll-in transition for the rotating slot.
    When a destination is too wide for the space left after the time/track/
    platform text, it now slides left to reveal the end, pauses, slides back to
    the start, pauses, and repeats - rather than being cut short with "...". A
    clip window keeps it strictly within its column so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
    [Departures Board.cpp]
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2026-08-18 Smooth slide-in for Odense bus lines; fix å/Å vertical alignment
    1. Odense bus board (drawOdenseGroupLine et al): each of the three group
    lines now slides its outgoing departure up and out while the incoming one
    slides up into place, mirroring the rotating "other departures" line on
    the DK Tog board exactly (same offsets/timing as departureBoardLoop()'s
    isScrollingService block) - previously each line just instantly blanked
    and redrew. Split drawOdenseGroupLine() into a lower-level
    drawOdenseGroupServiceAt(group, matches, matchCount, index, y) that draws
    at an arbitrary y with no side effects, used for both the static resting
    redraw and the two animated positions du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
    [Departures Board.cpp]
2026-08-18 Fix drawScrollingDestination() clobbering the caller's clip window
    drawScrollingDestination() unconditionally called u8g2.setMaxClipWindow() at
    its end, resetting clipping to the entire screen instead of restoring
    whatever the caller had set. On the rail board, the line-3 scroll-in
    transition (isScrollingService) sets its own clip window to bound the whole
    row's slide animation, then calls drawServiceLine() twice per frame (once
    for the outgoing departure, once for the incoming one) - each of those calls
    drawScrollingDestination() internally, which was blowing away that outer
    clip window mid-slide. That let content briefly escape the intended slide
    region, showing as visual artifacts between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
    [Departures Board.cpp]
2026-08-18 Simplify slide-transition clipping: re-assert outer clip per draw, not nested restore
    The previous fix (intersect-with-and-restore-the-caller's-clip-window inside
    drawScrollingDestination) was overly clever and introduced a new bug: text
    getting clipped to roughly 25% of its width during the line-3 slide
    transition. Replaced with a much simpler, easier-to-verify approach:
    drawScrollingDestination() goes back to plainly setting its own clip window
    and resetting to the full screen afterward (no nesting/restore logic at
    all) - and the two transition blocks that need a wider bound spanning both
    the outgoing and incoming draw (departureBoardLoop()'s isScrollingService,
    and the Odense per-group eq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
    [Departures Board.cpp]
2026-08-18 Stop the slide transition and ping-pong scroller from fighting over the clip window
    Three attempts at nesting/coordinating two separate clip windows (the
    transition's own row-bounding one, and the ping-pong scroller's per-draw
    horizontal one) all failed in different ways - restore-based nesting cut
    text to ~25% width, and re-asserting the outer window before each draw still
    left persistent artifacts above/below the row. Eliminated the conflict
    instead of trying to resolve it: added a suppressDestScrolling flag, set
    around the transition's two per-frame draw calls, that makes
    drawScrollingDestination() fall back to plain truncate-with-"..." (new
    drawTruncatedDestination() helper) and not touc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
    [Departures Board.cpp]
2026-08-19 Fix primary-line scroll getting reset by the via toggle; fix O-slash ghosting
    1. drawPrimaryService() alternates between showing the destination and the
    "via" text every few seconds (viaTimer). Since drawScrollingDestination()
    treats any text change as a reason to restart the scroll animation from
    the beginning, sharing one state between the two meant the animation got
    reset on every single toggle - often before a long destination had moved
    more than a few pixels, which read as permanently stuck/truncated rather
    than genuinely broken. Split into primaryDestScroll/primaryViaScroll so
    each tracks its own progress independently; switching between them no
    longer resets ei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
    [Departures Board.cpp]
2026-08-19 Fix line 1 scroll clip window cutting off most of the text vertically
    The previous fix for O-slash ghosting (clipTop, clamping the clip window's
    top edge up to LINE1) had a real bug: it raised the top bound without
    touching the bottom bound (still the old "y+4" heuristic, calibrated for a
    much larger negative-clamped-to-0 top). For the primary line specifically
    that shrank the effective clip window from about 16px tall down to just 3px
    (13 to 16), chopping off roughly the bottom two-thirds of every character
    while actively ping-pong scrolling - not just Ø, any text.
    Replaced the rowHeight+margin heuristic entirely with explicit clipTop/
    clipBottom parameters that each caller passes from it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
    [Departures Board.cpp]
2026-08-19 Stop constraining line 1 scroller's vertical axis - tight clip kept misbehaving
    Multiple attempts at a precise vertical clip window for the primary line's
    ping-pong scroller (LINE1..LINE2, then explicit clipTop/clipBottom) each
    produced a visibly smaller window than the maths predicted, still cutting
    off 70-80% of the text height while actively scrolling. Rather than keep
    guessing at exact pixel bounds for this one row/font/baseline combination,
    removed the vertical constraint entirely for it (clipTop=0,
    clipBottom=SCREEN_HEIGHT) - the only bound actually needed here is
    horizontal (stop the scrolling destination overlapping the time/track
    text), so give the vertical axis the full screen and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
    [Departures Board.cpp]
2026-08-19 Fetch more departures for Odense buses; exclude ones terminating at Odense/OBC
    1. MAXBOARDSERVICES 9 -> 24. All three Odense DK Bus groups (OBC Nord/OBC
    Syd/Ejlskovsgade) filter from the same shared fetch window, so with only
    9 total slots split three ways a quieter group would often come up
    empty even when it genuinely has upcoming departures further down the
    list that just didn't make the cut. This is a global constant (affects
    every mode's fetch depth and service[] storage, not just Odense buses),
    but the RAM cost is modest (checked against the actual build: 28.9% ->
    36.9%) and more departures to rotate through is a mild improvement
    everywhere, not a downside - the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
    [Departures Board.cpp]
2026-08-19 Compact Odense bus line format: "OBC N 35" and "14:32+5" instead of "Bus 35"/"Forventet 14:37"
    - Time column: "Forventet HH:MM" took up too much space. Now shows the
    scheduled time with a "+X" delay suffix (e.g. "14:32+5") when the
    realtime differs, computed as the minute delta between scheduled and
    realtime - no suffix at all when on time (no need to spell out
    "Rettidig"), "Aflyst" still shown plainly when cancelled.
    - Route prefix: replaced "Bus " with the line's own abbreviated group label
    ("OBC N"/"OBC S"/"Ejlskovsgade") ahead of the bare route number, e.g.
    "OBC N 35" instead of "Bus 35" - identifies which of the three areas a
    line is even without tracking screen position,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
    [Departures Board.cpp]
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2026-08-20 Redesign train icon; fix departed train staying on display after animation
    1. drawTrainIcon(): removed the coupling lines between cars (now just plain
    empty space), and redesigned the nose to taper from the roofline down to
    a point level with the bottom of the car - a side-on locomotive wedge,
    rather than the previous horizontally-centred arrowhead.
    2. Real bug fix: the animation was purely cosmetic - once it finished, it
    just redrew station.service[0], which is very likely still the exact
    departure that just "left" if the next real data fetch hasn't landed
    yet (Rejseplanen/National Rail only drop a departed service from their
    own next response, and the board's poll int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
    [Departures Board.cpp]
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2026-08-21 Train icon: zero-gap rounded cars, nose fixed to reach the bottom row
    - No gap between cars at all - drawRBox()'s rounded corners recess slightly
    at each seam on their own, giving visual separation without an actual
    pixel of space.
    - Body cars (and the front car's rectangular portion) now use drawRBox()
    instead of drawBox() for rounded outer corners.
    - The nose's bottom edge was landing 1px short of the cars' own bottom row
    - drawTriangle() apparently doesn't fill the exact horizontal bottom edge
    the way a filled rect does. Replaced with a manual bottom-anchored
    staircase of per-column drawVLine() calls, which guarantees every column
    (including the last) actually reaches y+carH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
    [Departures Board.cpp]
2026-08-21 Simplify train icon to three plain rectangles with a flush pointed nose
    After several rounds of hand-rolled rounded-corner pixel math that kept
    introducing its own bugs and never actually looked right, dropped rounding
    entirely: three plain sharp-cornered rectangles with a 1px gap between
    each, then a pointed nose on the front one.
    The nose is built one column at a time rather than via drawTriangle() -
    confirmed on real hardware that drawTriangle() left the bottom row 1px
    short of the rectangles' own bottom edge, so the point never sat flush.
    Each column is its own bottom-anchored vertical line, which guarantees
    every column (including the last) reaches exactly the same bottom row as
    the th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
    [Departures Board.cpp]
2026-08-22 Fix S-tog platform ranges getting truncated (e.g. "9-10" -> "9-1")
    Confirmed live at Kobenhavn H (S-tog stop id 8600626): rtTrack for S-tog
    departures is often a paired-platform range like "9-10" or "11-12", since
    several of that station's S-tog tracks share a physical island platform -
    never a single number the way UK platforms and DK Tog tracks usually are.
    Two separate 3-usable-character truncation points, both originally sized
    for short UK-style platform numbers:
    - rdService/rdiService.platform was char[4] - widened to char[8].
    - The "Spor %.3s"/"Plat %.3s" format strings in drawPrimaryService() and
    drawServiceLine() truncated to 3 chars even if the field held more -
    widened to %.7s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
    [Departures Board.cpp]
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2026-08-22 Add S-tog line-badge board style for København H
    Only when the current DK Rail station is København H and a service is
    actually S-tog (Rejseplanen catOut=="S-Tog") - a mixed board with other
    products selected still shows those normally.
    - Line-letter badge (rounded square, letter knocked out) replaces the
    scheduled time on the left of the primary/2nd/3rd departure rows.
    - A Letbane-style minute countdown replaces "Forventet HH:MM"/"Rettidig".
    Cancelled services still show "Aflyst".
    - The via-toggle (which for DK Rail shows the line/train-number label -
    redundant now that the badge shows the line letter permanently) is
    skipped for these rows.
    - "Stopper ved" (calling points) drops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
    [Departures Board.cpp]
2026-08-22 S-tog badge fixes + dedicated S-tog board mode
    - Fix badge letter centring: it was centred by the font's ADVANCE width/
    cell height, which bakes in per-letter side-bearing/spacing and doesn't
    match the actual ink - some letters looked centred, others didn't. Now
    reads each glyph's real (width, height, x/y-offset) straight from the
    font's raw data (same technique already used for the Danish accent-letter
    fix) and centres that tight ink box instead, for any letter/size.
    - Fix Danish letters (æøå) going missing from the header station name: the
    user-typed friendly name (dkName/letbaneName/stogName/dkBusName) comes
    from the web config form as UTF-8, unlike API-derived text whic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
    [Departures Board.cpp]
2026-08-22 Fix S-tog badge centring: missing +1 in u8g2's PosTop vref, and bolden line 1's badge
    Traced the residual centring error to u8g2_font_calc_vref_top() in u8g2's
    own source: PosTop mode adds font_ref_ascent+1 (not just font_ref_ascent)
    before handing y off to the glyph decoder. drawMixedStr()'s existing
    yShift correction never needed this +1 because it's a *difference*
    between two fonts' ascents (the +1 is on both sides and cancels), but
    drawSTogBadge()'s ink-box centring computes an absolute position, so the
    missing +1 was a real, consistent 1px vertical error - confirmed by
    reading the actual u8g2_font.c source rather than guessing again.
    Also switched the primary (line 1) badge to u8g2_fon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
    [Departures Board.cpp]
2026-08-23 S-tog badge fixes + dedicated S-tog board mode
    - Badge corners: reduced radius 2->1. u8g2's box/disc drawing is strictly
    1-bit (confirmed by reading u8g2_box.c/u8g2_circle.c) - no pixel is ever
    drawn at partial intensity, so the 'not fully lit' look wasn't a fill bug;
    at r=2 the quarter-circle corner notch is a big enough fraction of a
    9-12px badge to read as gaps. r=1 keeps a visibly rounded corner while
    the fill reads solid.
    - Countdown now has a genuine half-minute step: sTogCountdownMinutes()
    (whole minutes only) replaced with sTogCountdownText(), which computes
    the delta down to the second (timeinfo.tm_sec, not just tm_min) and
    shows "Nu" (due, <15s), "1/2 min" (15-44s)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
    [Departures Board.cpp]
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2026-08-23 Default 'show date' on for new setups, add Swedish letter support
    - writeDefaultConfig() now writes showDate:true for a fresh board's very
    first config.json (was false). Existing saved configs are untouched -
    this only changes what a new/reset board starts with.
    - isDanishAccentByte() now also recognises Swedish ä/Ä/ö/Ö (Latin-1 0xE4/
    0xC4/0xF6/0xD6), so Swedish trains (SJ/Snälltåg) running through
    Danish stations render correctly too. å/Å were already covered (shared
    with Danish); the UTF8->Latin1 conversion path is already byte-generic
    so it needed no change, only the accent-substitution gate did.
    [Departures Board.cpp]
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2026-08-23 Translate remaining on-screen prompts to Danish
    The setup/error/notification screens (Wi-Fi setup, invalid API key,
    invalid stop id, no data, firmware update progress/warnings, mode-switch
    transition) were left in English during the earlier UK-mode removal -
    this covers the rest of them. Uses centreMixedText() (already used
    throughout the board's own Danish rendering) wherever the translation
    needs \xE6/\xF8/\xE5, since the custom fonts have no accented glyphs of
    their own.
    Also found and removed a second piece of dead UK code the mode-removal
    pass missed: drawUndergroundService()'s TfL-style "Due"/"X min(s)"
    countdown branch (keyed off station.origin/service[0].timeToStation,
    both TfL-only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
    [Departures Board.cpp]
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2026-08-24 Widen S-tog badge for multi-letter lines (Bx), bump version to 3.7
    - drawSTogBadge() now measures the label's ink width before drawing
    the box: single-letter lines (A, B, C, E, F, H) stay a square
    exactly as before, but a label that doesn't fit (currently only
    the Bx line) widens the badge into a small rounded rectangle,
    matching how Copenhagen's own signage shows Bx as a pill rather
    than a square.
    - The function now returns its actual drawn width so the two call
    sites (drawPrimaryService/drawServiceLine) can position the
    destination text correctly instead of assuming a fixed width.
    - Bump VERSION_MINOR to 7 so both boards pick this up automatically.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
    [Departures Board.cpp]
2026-08-24 Remove startup splash/Gadec branding, rename product, reset versioning to 2.0
    - Remove the 5-second Gadec logo/notice boot splash entirely (setup()
    now goes straight to the startup heading) and delete the now-unused
    gadeclogo bitmap (include/gfx/xbmgfx.h).
    - Startup screen now reads "Danske afgangstavler" instead of
    "Departures Board".
    - Collapse the dual firmware/webapp version scheme (VERSION_MAJOR.MINOR
    / WEBAPPVER_MAJOR.MINOR, tag format "B3.7-W3.4") into a single plain
    "major.minor" version, since the web UI has been embedded directly
    into firmware.bin for a while now and a separate web version number
    no longer means anything. Updated the release-tag parser, /firmware
    en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
    [Departures Board.cpp]
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2026-08-24 Fix Tog init progress bar to say "Initialiserer Tog", bump to 2.1
    Was showing "Initialiserer Rejseplanen" while the other three modes
    say "Initialiserer Letbane"/"S-tog" etc. - now consistent.
    [Departures Board.cpp]
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

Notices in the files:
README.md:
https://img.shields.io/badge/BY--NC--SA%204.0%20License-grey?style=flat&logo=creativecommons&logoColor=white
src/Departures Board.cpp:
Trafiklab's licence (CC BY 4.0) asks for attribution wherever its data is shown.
